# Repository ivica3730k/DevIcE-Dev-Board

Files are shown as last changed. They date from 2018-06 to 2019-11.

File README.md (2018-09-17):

# DevIcE-Development-Board
All software materials for DevIcE Development board,created by Ivica 9A3ICE

IoT development board currently is based on ESP8266,including:
SMPS power supply
16 digital IO ports
6 ADC ports
5 DAC outputs
RTC clock
Optional HC-05 bluetooth

...all packed in small form factor of 100*60mm.

Board easly programmable trough Arduino IDE

Full board plans available in other Repo.

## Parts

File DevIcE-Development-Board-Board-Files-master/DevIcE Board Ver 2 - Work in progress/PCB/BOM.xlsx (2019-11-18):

Schematic Reference | Manufacter | Part Number | Value | Description
J1 | Wurth Eletronics Inc. | ‎694106301002 (https://www.digikey.com/product-detail/en/wurth-electronics-inc/694106301002/732-5930-ND/5047522) |  | DC-IN JACK
U1 | Vishay Siliconix | SI2301CDS-T1-GE3CT-ND |  | MOSFET P-CH 20V 3.1A SOT23-3
D1 | Comchip Technology | ‎CDBA340-HF (https://www.digikey.com/product-detail/en/comchip-technology/CDBA340-HF/641-1748-1-ND/5400722) | 40V 3A | DIODE SCHOTTKY 40V 3A DO214AC
IC1 | Texas Instruments‎ | ‎LM2575S-3.3/NOPB‎ | 3.3V 1A | LM2575-3V3 PSU
L1 | ‎Bourns Inc.‎ | ‎SRR1280-331K (https://www.digikey.com/product-detail/en/bourns-inc/SRR1280-331K/SRR1280-331KLCT-ND/2127441) | 330uH | FIXED IND 330UH 1.1A 600 MOHM
ZD1 | Panasonic Electronic Components‎ | ‎DZ2J100M0L (https://www.digikey.com/product-detail/en/panasonic-electronic-components/DZ2J100M0L/DZ2J100M0LCT-ND/2214312) | 10V | DIODE ZENER 10V 200MW SMINI2
R1 | Vishay Dale‎ | CRCW020110K0FKED | 10K | RES SMD 10K OHM 1% 1/20W 0201
R2 | Vishay Dale‎ | ‎CRCW0201100RFKED (https://www.digikey.com/product-detail/en/vishay-dale/CRCW0201100RFKED/541-100AABCT-ND/1968157) | 100R | RES SMD 100 OHM 1% 1/20W 0201
R3 | Vishay Dale‎ | ‎CRCW02014K70FKED‎ | 4K7 | RES SMD 4.7K OHM 1% 1/20W 0201
R4 | Vishay Dale‎ | ‎CRCW02014K70FKED‎ | 4K7 | RES SMD 4.7K OHM 1% 1/20W 0201
R5 | Vishay Dale‎ | ‎CRCW02014K70FKED‎ | 4K7 | RES SMD 4.7K OHM 1% 1/20W 0201
R6 | Vishay Dale‎ | ‎CRCW02014K70FKED‎ | 4K7 | RES SMD 4.7K OHM 1% 1/20W 0201
U2 | Panasonic Electronic Components‎ | ‎EXB-38V103JV (https://www.digikey.com/product-detail/en/panasonic-electronic-components/EXB-38V103JV/Y9103CT-ND/256604) | 4X10K | RES ARRAY 4 RES 10K OHM 1206
U3 | Panasonic Electronic Components‎ | ‎EXB-38V103JV (https://www.digikey.com/product-detail/en/panasonic-electronic-components/EXB-38V103JV/Y9103CT-ND/256604) | 4X10K | RES ARRAY 4 RES 10K OHM 1206
U4 | Panasonic Electronic Components‎ | ‎EXB-38V103JV (https://www.digikey.com/product-detail/en/panasonic-electronic-components/EXB-38V103JV/Y9103CT-ND/256604) | 4X10K | RES ARRAY 4 RES 10K OHM 1206
IC2 | ‎Microchip Technology‎ | ‎MCP23017T-E/SO‎ |  | IC I/O EXPANDER I2C 16B 28SOIC
IC3 | ‎NXP USA Inc.‎ | ‎PCA9685PW,118 (https://www.digikey.com/product-detail/en/nxp-usa-inc/PCA9685PW,118/568-11925-1-ND/5221902) |  | IC LED DRIVER RGBA 28-TSSOP
C1 | Panasonic Electronic Components‎ | ‎EEE-1HA470XP‎ | 47uF 50V | CAP ALUM 47UF 20% 50V SMD
C2 | ‎Samsung Electro-Mechanics‎ | ‎CL03A104KQ3NNNC (https://www.digikey.com/product-detail/en/samsung-electro-mechanics/CL03A104KQ3NNNC/1276-1013-1-ND/3889099) | 100nF 6.3V | CAP CER 0.1UF 6.3V X5R 0201
C3 | ‎Samsung Electro-Mechanics‎ | ‎CL03A104KQ3NNNC (https://www.digikey.com/product-detail/en/samsung-electro-mechanics/CL03A104KQ3NNNC/1276-1013-1-ND/3889099) | 100nF 6.3V | CAP CER 0.1UF 6.3V X5R 0201
C4 | Panasonic Electronic Components‎ | ‎EEE-0JA221WP‎ | 220uF 6.3V | CAP ALUM 220UF 20% 6.3V SMD
C5 | Panasonic Electronic Components‎ | ‎EEE-0JA221WP‎ | 220uF 6.3V | CAP ALUM 220UF 20% 6.3V SMD
LED1 | ‎Kingbright‎ | ‎APTR3216CGCK (https://www.digikey.com/product-detail/en/kingbright/APTR3216CGCK/754-1167-1-ND/1747884) | GRN | LED GREEN CLEAR CHIP SMD

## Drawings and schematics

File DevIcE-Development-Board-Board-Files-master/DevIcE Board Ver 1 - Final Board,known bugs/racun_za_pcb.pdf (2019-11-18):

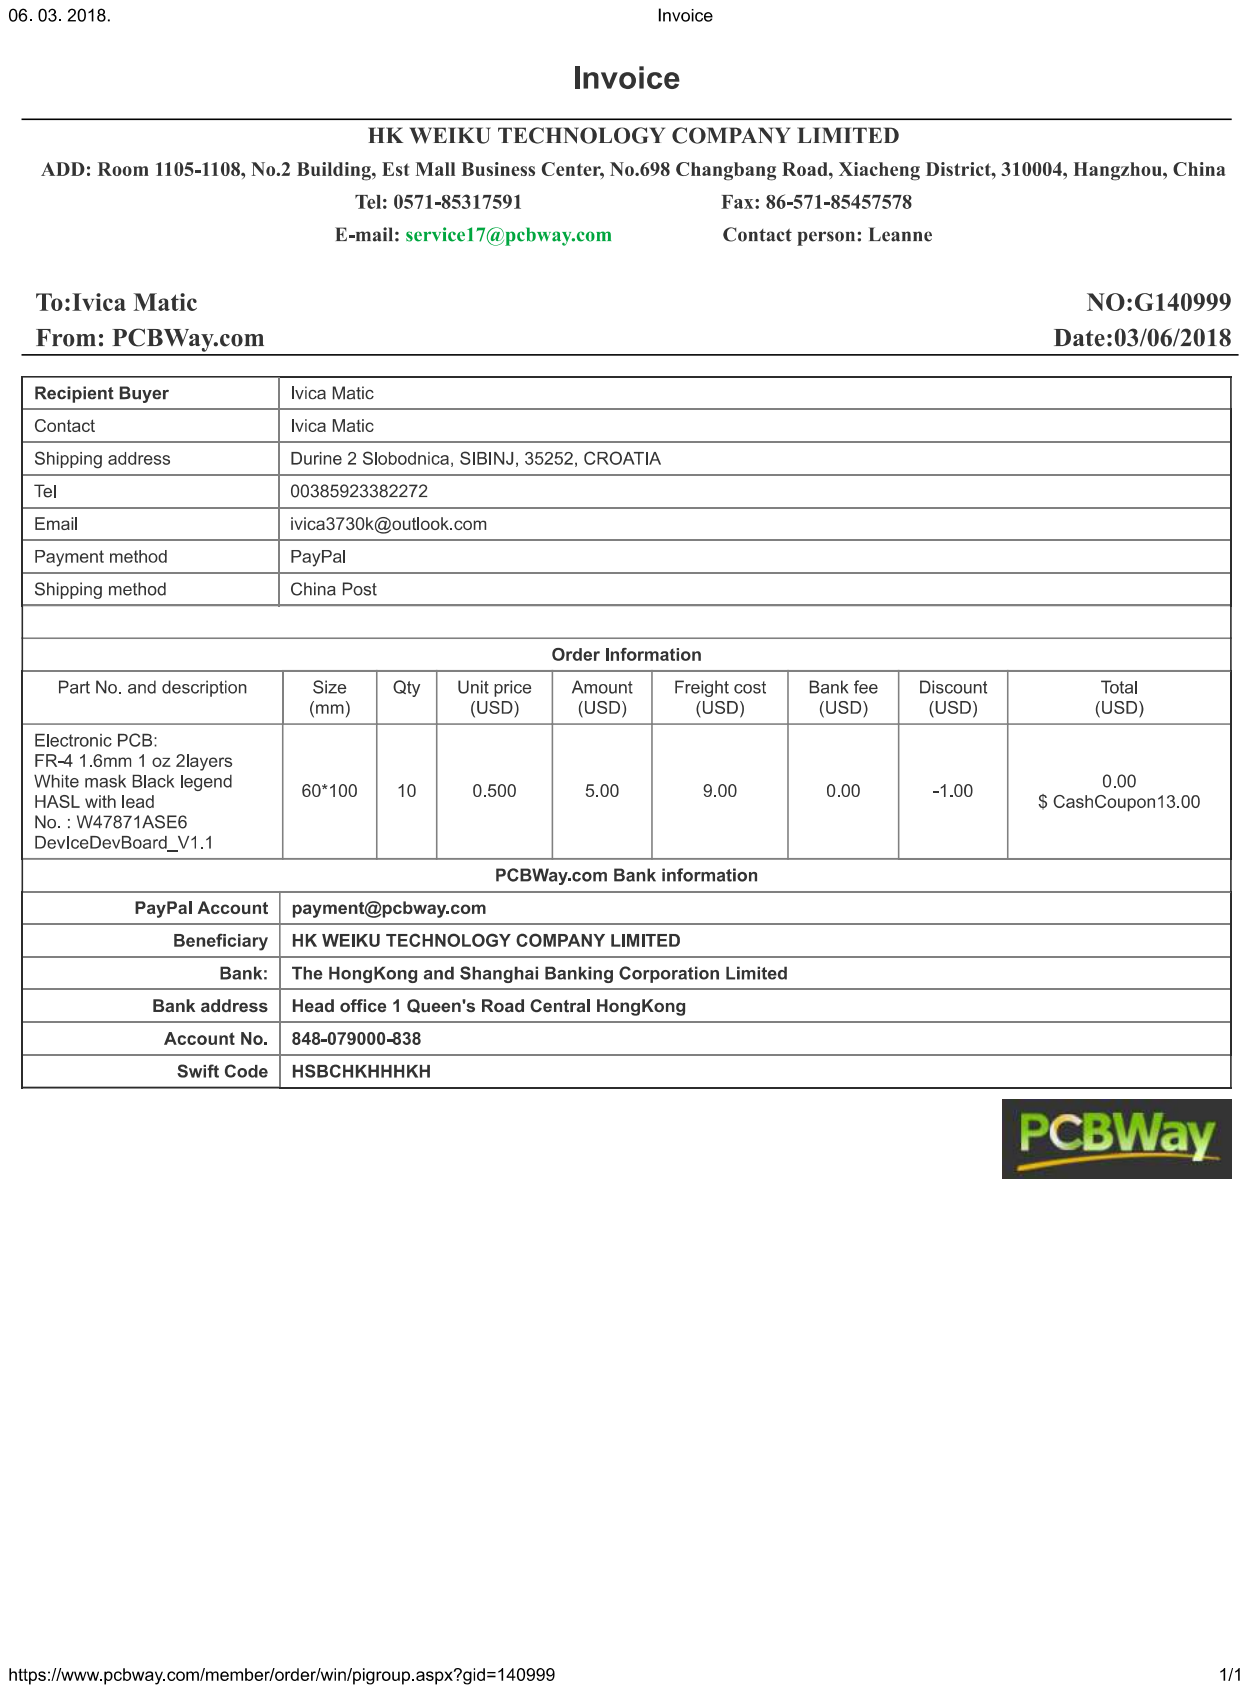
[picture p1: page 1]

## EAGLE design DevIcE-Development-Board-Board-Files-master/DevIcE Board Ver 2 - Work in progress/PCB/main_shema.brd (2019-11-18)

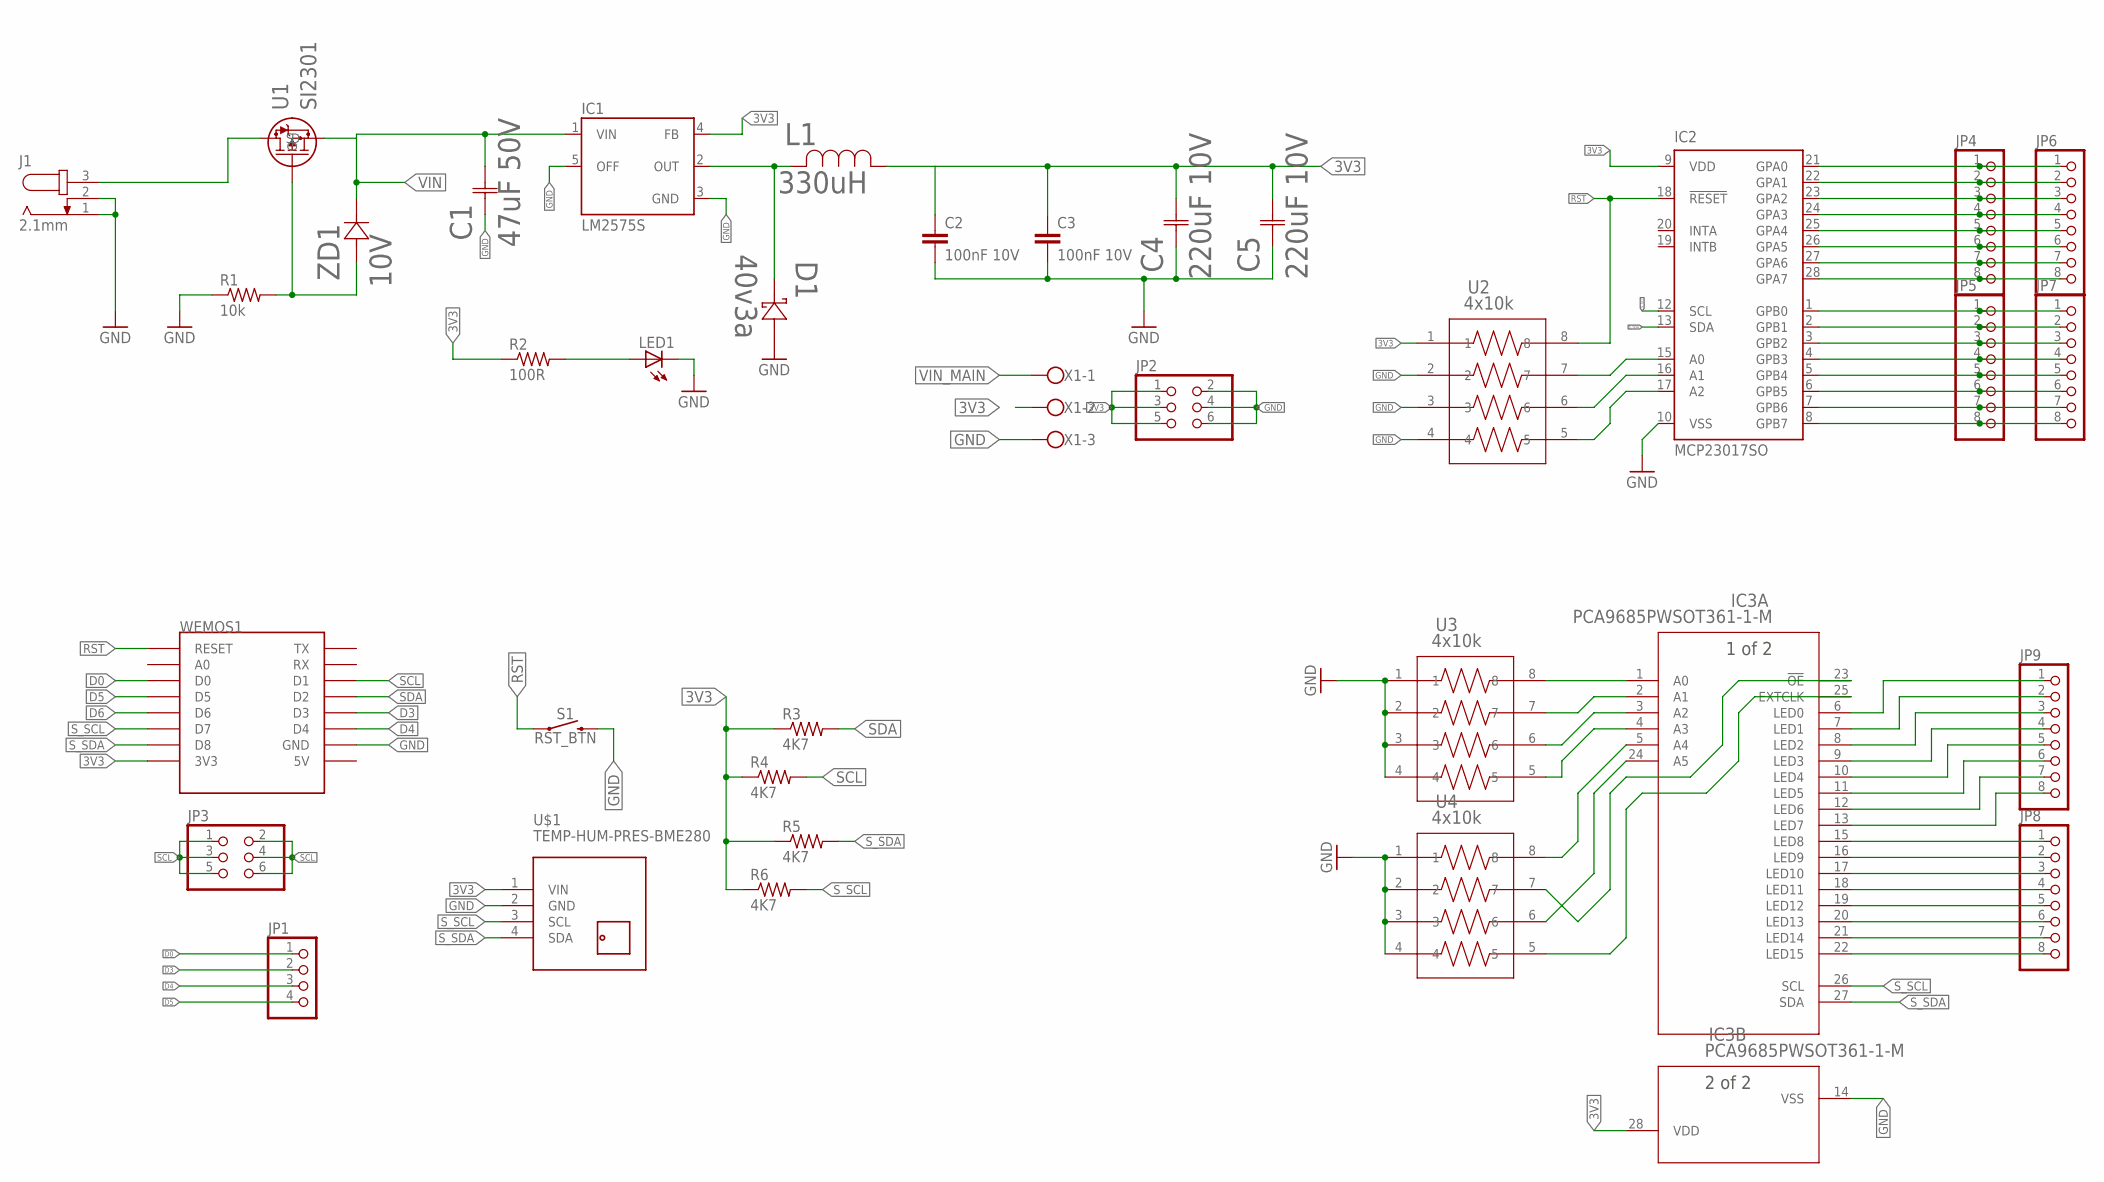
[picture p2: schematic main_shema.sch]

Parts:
C1: 47uF 50V; CAP_EEE_D8-M
C2, C3: 100nF 10V; C0603
C4, C5: 220uF 10V; CAP_EEE_D-M
D1: 40v3a; CDBA-HF-M
IC1: LM2575S; TO263-5
IC2: MCP23017SO; SO28W
IC3: PCA9685PWSOT361-1-M; SOT361-1-M
J1: 2.1mm; SPC4078
JP1: PINHD-1X4; 1X04
JP2, JP3: PINHD-2X3; 2X03
JP4, JP5, JP6, JP7: PINHD-1X8; 1X08
JP8, JP9: PINHD-1X8/LONG; 1X08
L1: 330uH; IND_BOURNS_SRR1280
LED1: LED_E; LED_1206
R1: 10k; R0603
R2: 100R; R0603
R3, R4, R5, R6: 4K7; R0603
S1: RST_BTN; TACTILE_SWITCH_PTH_6.0MM
U1: SI2301; TO-236-M
U2: 4x10k; C_ARRAY_EXB38V
U3, U4: 4x10k; C_ARRAY_EXB38V-M
U$1: TEMP-HUM-PRES-BME280
WEMOS1: WEMOS-D1-MINI
X1: W237-103
ZD1: 10V; SMINI2-F5-B-M

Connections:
3V3: C2.1, C3.1, C4.2 (22), C5.2 (22), IC1.4 (FB), IC2.9 (VDD), IC3.28 (VDD), JP2.1, JP2.3, JP2.5, L1.1, R2.1, R3.1, R4.1, R5.1, R6.1, U2.1, U$1.1 (VIN), WEMOS1.3V3, X1.2
D0: JP1.1, WEMOS1.D0
D3: JP1.2, WEMOS1.D3
D4: JP1.3, WEMOS1.D4
D5: JP1.4, WEMOS1.D5
D6: WEMOS1.D6
GND: C1.1 (11), C2.2, C3.2, C4.1 (11), C5.1 (11), D1.2 (22), IC1.3 (GND), IC1.5 (OFF), IC2.10 (VSS), IC3.14 (VSS), J1.1, J1.2, JP2.2, JP2.4, JP2.6, LED1.C, R1.1, S1.3 (2), U2.2, U2.3, U2.4, U3.1, U3.2, U3.3, U3.4, U4.1, U4.2, U4.3, U4.4, U$1.2 (GND), WEMOS1.GND, X1.3
unnamed: LED1.A, R2.2
unnamed: R1.2, U1.1 (G), ZD1.2 (22)
unnamed: IC2.21 (GPA0), JP4.1, JP6.1
unnamed: IC2.22 (GPA1), JP4.2, JP6.2
unnamed: IC3.6 (LED0), JP9.1
unnamed: IC3.7 (LED1), JP9.2
unnamed: IC3.8 (LED2), JP9.3
unnamed: D1.1 (11), IC1.2 (OUT), L1.2
unnamed: IC2.15 (A0), U2.7
unnamed: IC3.9 (LED3), JP9.4
unnamed: IC2.23 (GPA2), JP4.3, JP6.3
unnamed: IC2.16 (A1), U2.6
unnamed: IC2.17 (A2), U2.5
unnamed: IC3.10 (LED4), JP9.5
unnamed: IC2.24 (GPA3), JP4.4, JP6.4
unnamed: IC2.25 (GPA4), JP4.5, JP6.5
unnamed: IC2.26 (GPA5), JP4.6, JP6.6
unnamed: IC3.11 (LED5), JP9.6
unnamed: IC3.12 (LED6), JP9.7
unnamed: IC3.13 (LED7), JP9.8
unnamed: IC2.27 (GPA6), JP4.7, JP6.7
unnamed: IC2.28 (GPA7), JP4.8, JP6.8
unnamed: IC2.1 (GPB0), JP5.1, JP7.1
unnamed: IC2.2 (GPB1), JP5.2, JP7.2
unnamed: IC2.3 (GPB2), JP5.3, JP7.3
unnamed: IC2.4 (GPB3), JP5.4, JP7.4
unnamed: IC2.5 (GPB4), JP5.5, JP7.5
unnamed: IC2.6 (GPB5), JP5.6, JP7.6
unnamed: IC2.7 (GPB6), JP5.7, JP7.7
unnamed: IC2.8 (GPB7), JP5.8, JP7.8
unnamed: IC3.15 (LED8), JP8.1
unnamed: IC3.16 (LED9), JP8.2
unnamed: IC3.17 (LED10), JP8.3
unnamed: IC3.18 (LED11), JP8.4
unnamed: IC3.19 (LED12), JP8.5
unnamed: IC3.20 (LED13), JP8.6
unnamed: IC3.21 (LED14), JP8.7
unnamed: IC3.22 (LED15), JP8.8
unnamed: IC3.1 (A0), U3.8
unnamed: IC3.2 (A1), U3.7
unnamed: IC3.3 (A2), U3.6
unnamed: IC3.4 (A3), U3.5
unnamed: IC3.5 (A4), U4.8
unnamed: IC3.24 (A5), U4.6
unnamed: IC3.23 (!OE), U4.7
unnamed: IC3.25 (EXTCLK), U4.5
RST: IC2.18 (!RESET), S1.1, U2.8, WEMOS1.RESET
SCL: JP3.1, JP3.3, JP3.5, R4.2, WEMOS1.D1
SDA: JP3.2, JP3.4, JP3.6, R3.2, WEMOS1.D2
S_SCL: IC2.12 (SCL), IC3.26 (SCL), R6.2, U$1.3 (SCL), WEMOS1.D7
S_SDA: IC2.13 (SDA), IC3.27 (SDA), R5.2, U$1.4 (SDA), WEMOS1.D8
VIN: C1.2 (22), IC1.1 (VIN), U1.2 (S), ZD1.1 (11)
VIN_MAIN: J1.3, U1.3 (D), X1.1

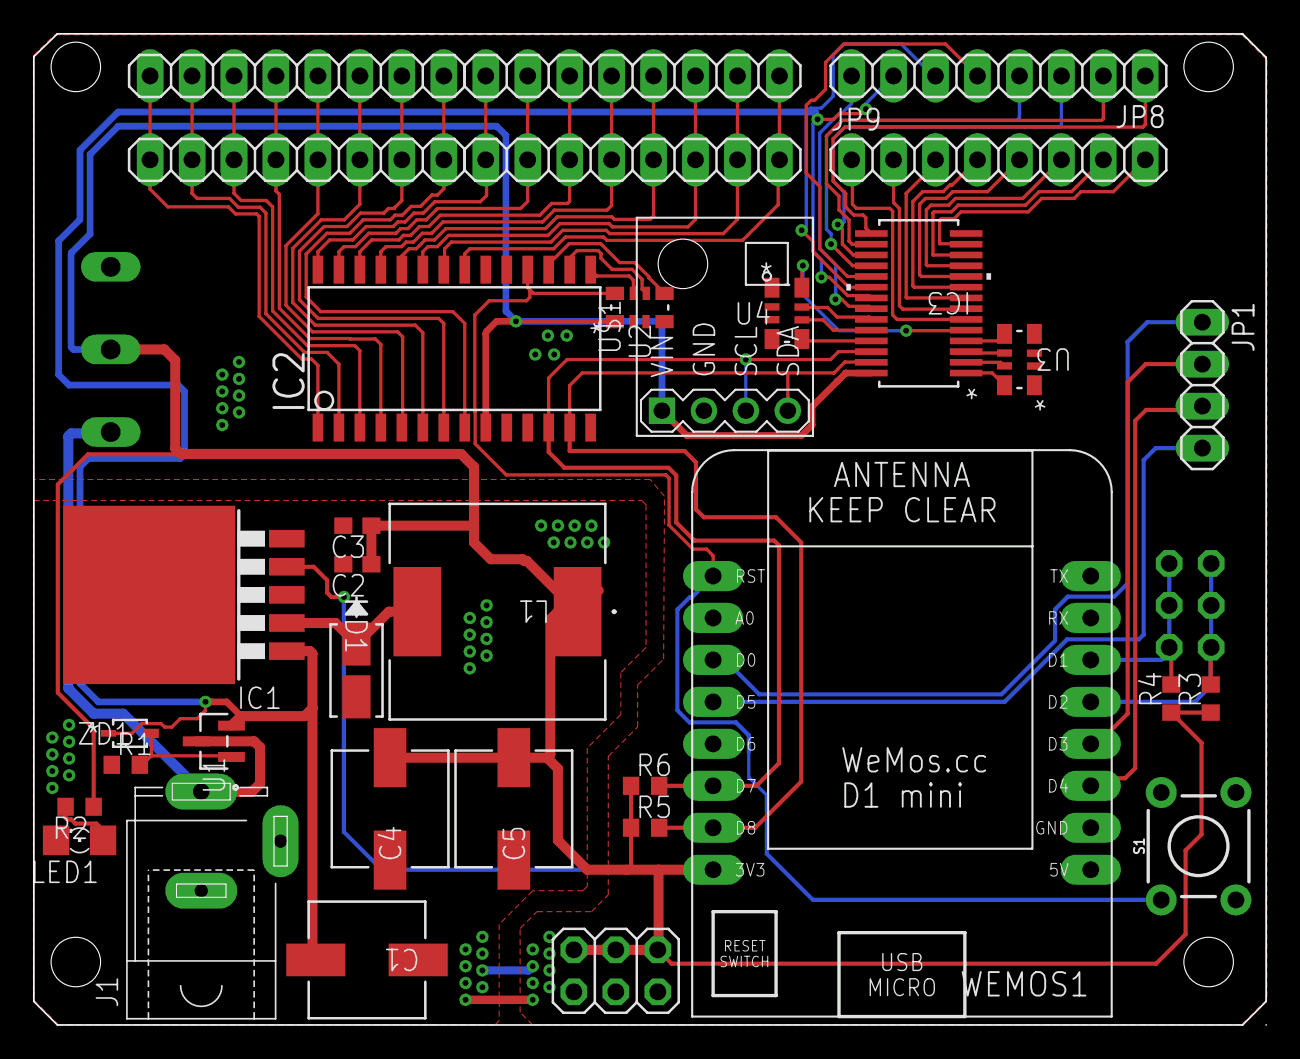
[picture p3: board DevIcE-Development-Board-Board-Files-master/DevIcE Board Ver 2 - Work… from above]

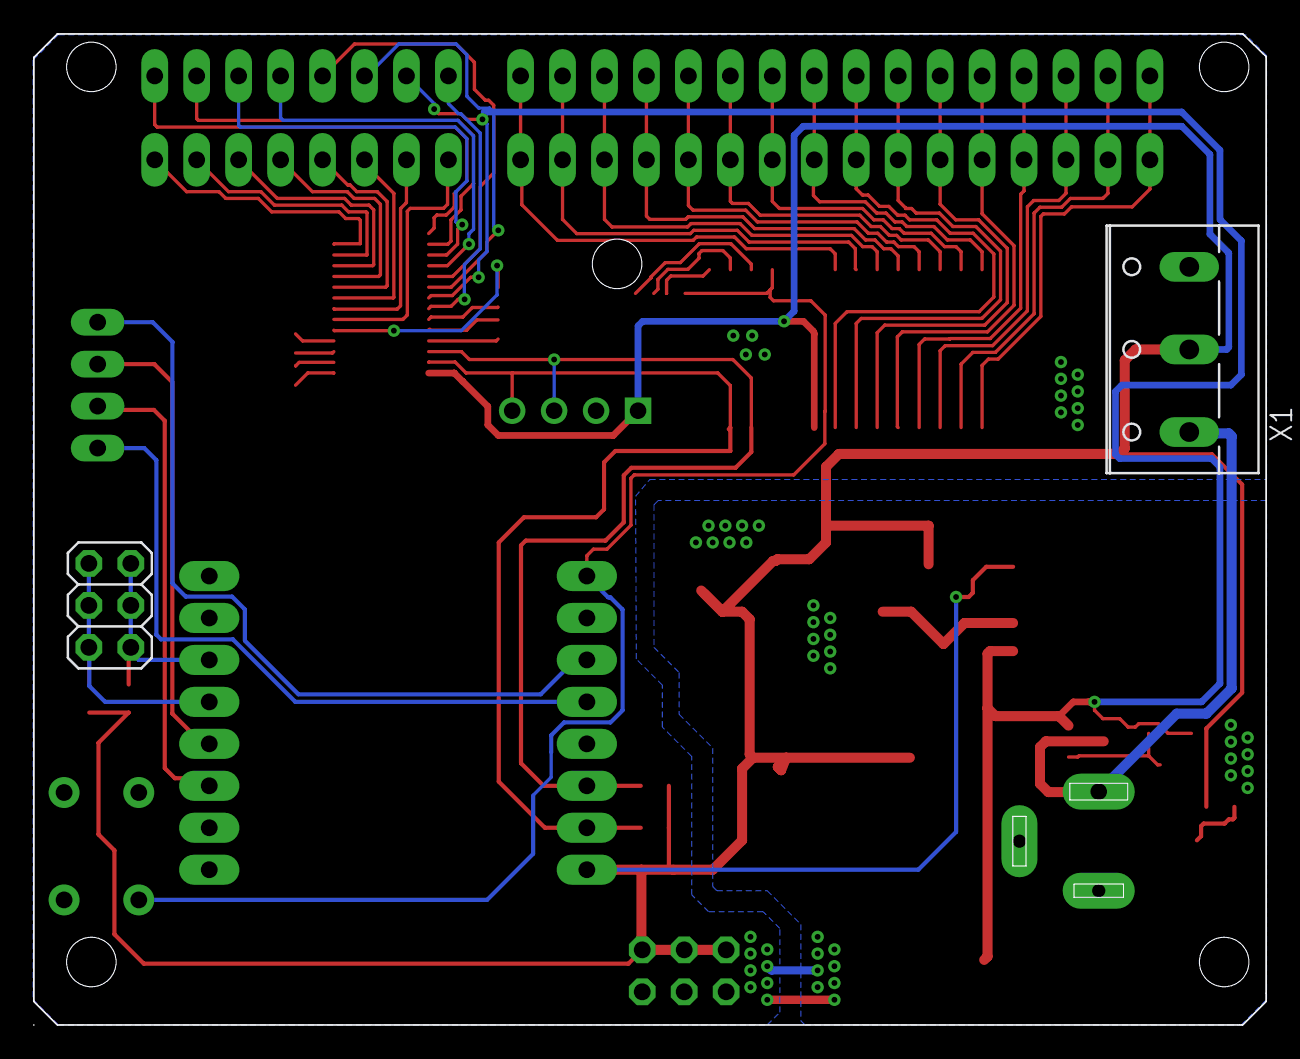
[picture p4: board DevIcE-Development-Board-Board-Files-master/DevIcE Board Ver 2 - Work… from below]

Board: 2 copper layers, 74.6 x 60.0 mm, 36 parts (2 on the bottom side), 59 nets.

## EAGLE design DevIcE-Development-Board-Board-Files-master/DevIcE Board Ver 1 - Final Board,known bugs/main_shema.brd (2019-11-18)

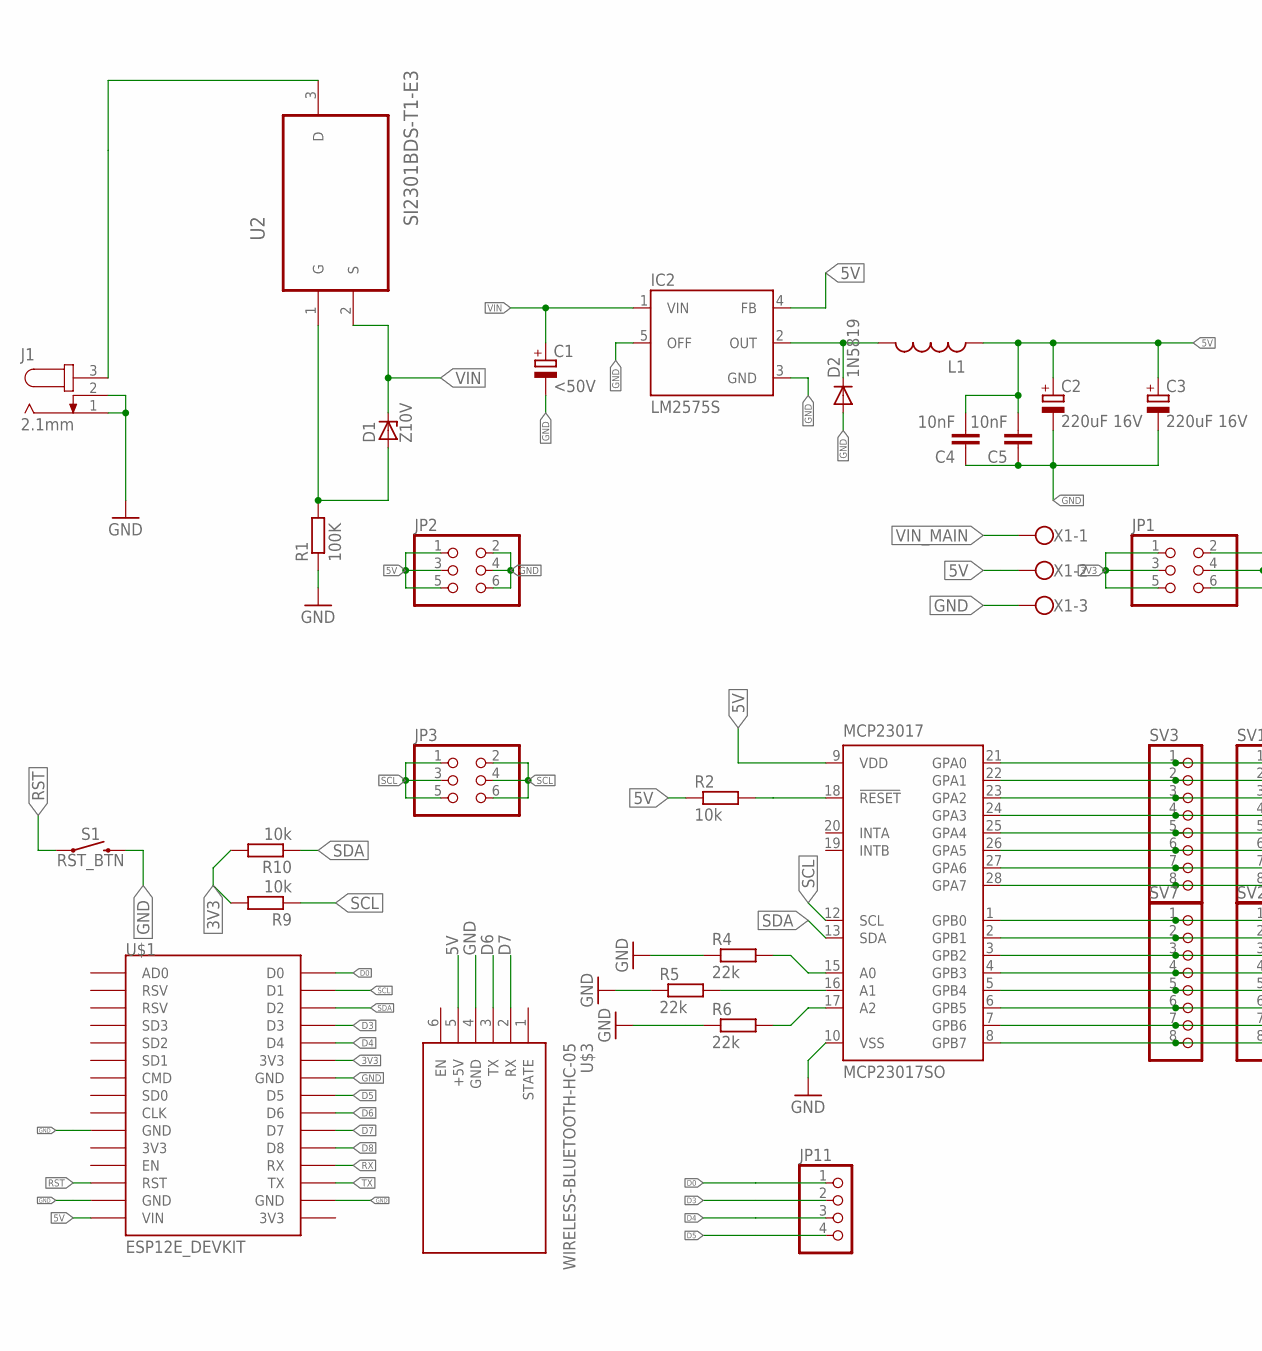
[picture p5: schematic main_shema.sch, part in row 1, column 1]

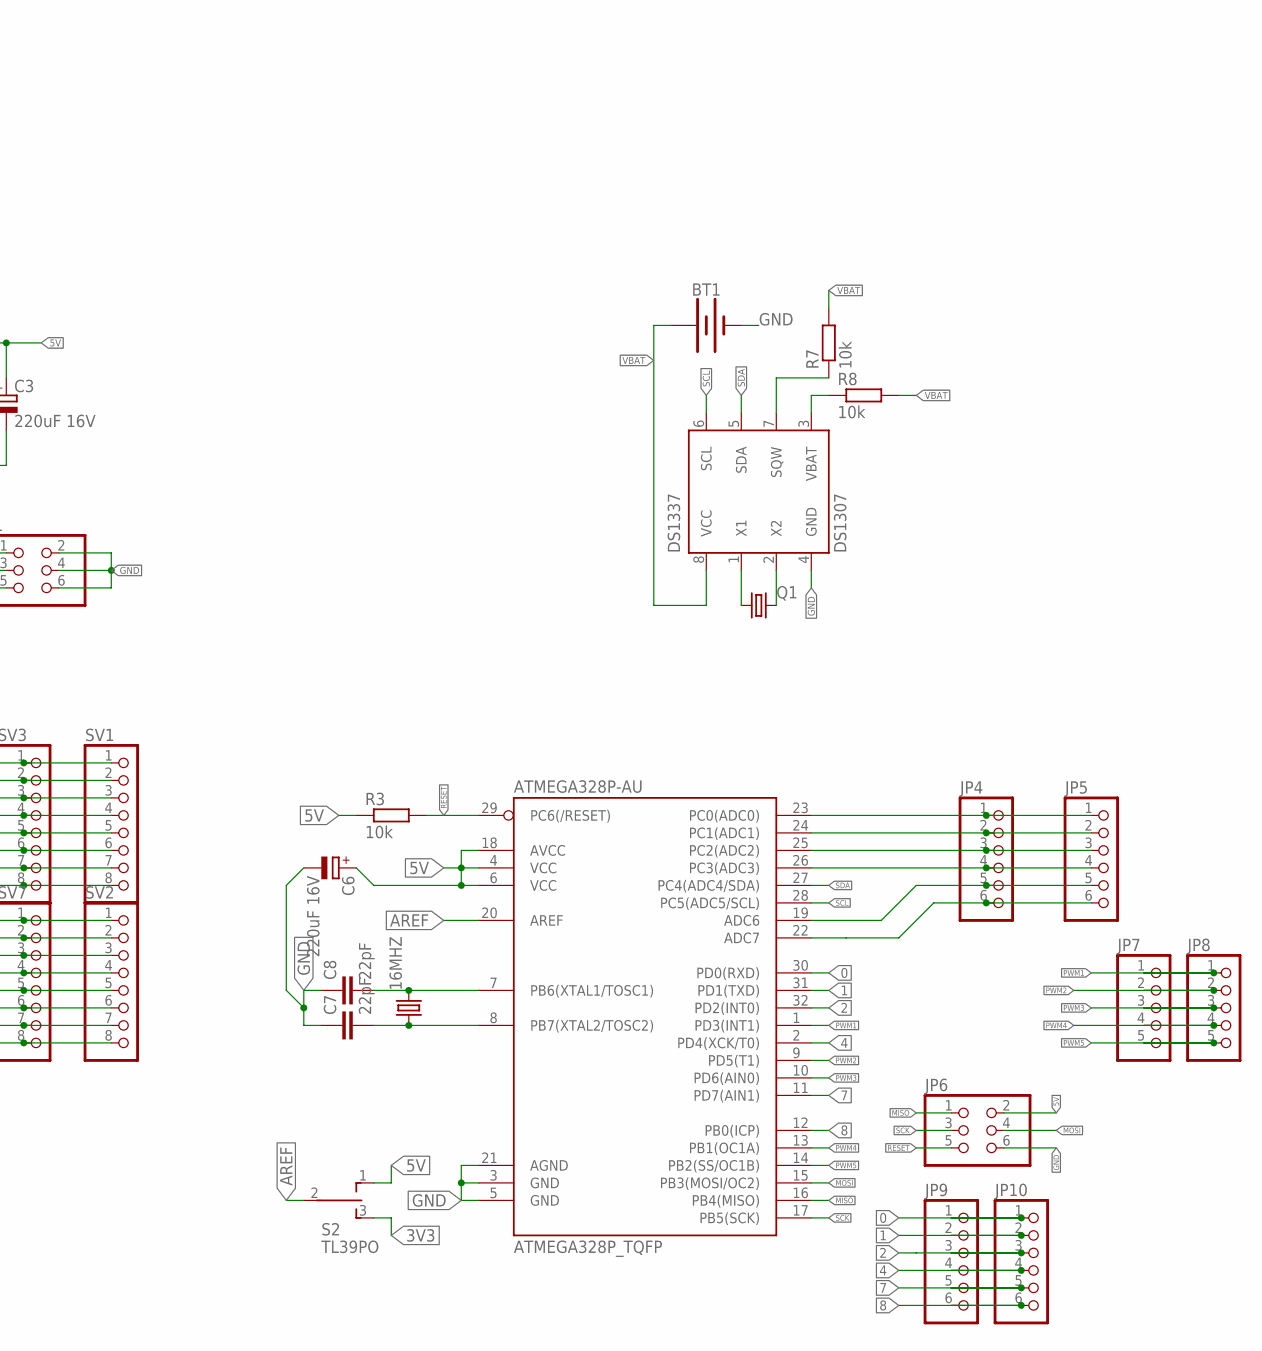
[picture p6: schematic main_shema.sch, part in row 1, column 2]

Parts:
16MHZ: CRYSTALHC49S; HC49/S
ATMEGA328P-AU: ATMEGA328P_TQFP; TQFP32-08
BT1: BATTERY-20MM_PTH; BATTCOM_20MM_PTH
C1: <50V; E3,5-8
C2, C3, C6: 220uF 16V; E2-5
C4, C5: 10nF; C025-024X044
C7, C8: 22pF; C025-024X044
D1: Z10V; DO35Z10
D2: 1N5819; DO41-10
DS1337: DS1307; DIL08
IC2: LM2575S; TO263-5
J1: 2.1mm; SPC4078
JP1, JP2, JP3, JP6: PINHD-2X3; 2X03
JP4, JP5, JP9, JP10: PINHD-1X6; 1X06
JP7, JP8: PINHD-1X5; 1X05
JP11: PINHD-1X4; 1X04
L1: MSS1260
MCP23017: MCP23017SO; SO28W
Q1: CRYSTALTC38H; TC38H
R1: 100K; R1206
R2, R3, R7, R8, R9, R10: 10k; R1206
R4, R5, R6: 22k; R1206
S1: RST_BTN; TACTILE_SWITCH_PTH_6.0MM
S2: TL39PO; TL3XPO
SV1, SV2, SV3, SV7: PINHD-1X8; 1X08
U2: SI2301BDS-T1-E3; SOT95P237X112-3N
U$1: ESP12E_DEVKIT
U$3: WIRELESS-BLUETOOTH-HC-05
X1: W237-103

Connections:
0: ATMEGA328P-AU.30 (PD0(RXD)), JP9.1, JP10.1
1: ATMEGA328P-AU.31 (PD1(TXD)), JP9.2, JP10.2
2: ATMEGA328P-AU.32 (PD2(INT0)), JP9.3, JP10.3
3V3: JP1.1, JP1.3, JP1.5, R9.2, R10.2, S2.3 (S), U$1.3V3@1 (3V3)
4: ATMEGA328P-AU.2 (PD4(XCK/T0)), JP9.4, JP10.4
5V: ATMEGA328P-AU.4 (VCC), ATMEGA328P-AU.6 (VCC), ATMEGA328P-AU.18 (AVCC), C2.+, C3.+, C4.2, C5.2, C6.+, IC2.4 (FB), JP2.1, JP2.3, JP2.5, JP6.2, L1.P$2, MCP23017.9 (VDD), R2.1, R3.1, S2.1 (O), U$1.VIN, U$3.5 (+5V), X1.2
7: ATMEGA328P-AU.11 (PD7(AIN1)), JP9.5, JP10.5
8: ATMEGA328P-AU.12 (PB0(ICP)), JP9.6, JP10.6
AREF: ATMEGA328P-AU.20 (AREF), S2.2
D0: JP11.1, U$1.D0
D3: JP11.2, U$1.D3
D4: JP11.3, U$1.D4
D5: JP11.4, U$1.D5
D6: U$1.D6, U$3.3 (TX)
D7: U$1.D7, U$3.2 (RX)
D8: U$1.D8
GND: ATMEGA328P-AU.3 (GND), ATMEGA328P-AU.5 (GND), ATMEGA328P-AU.21 (AGND), BT1.2 (-), C1.-, C2.-, C3.-, C4.1, C5.1, C6.-, C7.1, C8.1, D2.A, DS1337.4 (GND), IC2.3 (GND), IC2.5 (OFF), J1.1, J1.2, JP1.2, JP1.4, JP1.6, JP2.2, JP2.4, JP2.6, JP6.6, MCP23017.10 (VSS), R1.1, R4.1, R5.1, R6.1, S1.3 (2), U$1.GND@0 (GND), U$1.GND@1 (GND), U$1.GND@2 (GND), U$1.GND@3 (GND), U$3.4 (GND), X1.3
MISO: ATMEGA328P-AU.16 (PB4(MISO)), JP6.1
MOSI: ATMEGA328P-AU.15 (PB3(MOSI/OC2)), JP6.4
unnamed: DS1337.1 (X1), Q1.1
unnamed: D1.A, R1.2, U2.1 (G)
unnamed: MCP23017.21 (GPA0), SV1.1, SV3.1
unnamed: MCP23017.22 (GPA1), SV1.2, SV3.2
unnamed: MCP23017.15 (A0), R4.2
unnamed: MCP23017.16 (A1), R5.2
unnamed: MCP23017.17 (A2), R6.2
unnamed: D2.C, IC2.2 (OUT), L1.P$1
unnamed: DS1337.2 (X2), Q1.2
unnamed: ATMEGA328P-AU.22 (ADC7), JP4.6, JP5.6
unnamed: MCP23017.23 (GPA2), SV1.3, SV3.3
unnamed: DS1337.3 (VBAT), R8.1
unnamed: DS1337.7 (SQW), R7.1
unnamed: MCP23017.24 (GPA3), SV1.4, SV3.4
unnamed: MCP23017.25 (GPA4), SV1.5, SV3.5
unnamed: MCP23017.26 (GPA5), SV1.6, SV3.6
unnamed: MCP23017.18 (!RESET), R2.2
unnamed: 16MHZ.2, ATMEGA328P-AU.7 (PB6(XTAL1/TOSC1)), C8.2
unnamed: 16MHZ.1, ATMEGA328P-AU.8 (PB7(XTAL2/TOSC2)), C7.2
unnamed: MCP23017.27 (GPA6), SV1.7, SV3.7
unnamed: MCP23017.28 (GPA7), SV1.8, SV3.8
unnamed: MCP23017.1 (GPB0), SV2.1, SV7.1
unnamed: MCP23017.2 (GPB1), SV2.2, SV7.2
unnamed: MCP23017.3 (GPB2), SV2.3, SV7.3
unnamed: MCP23017.4 (GPB3), SV2.4, SV7.4
unnamed: MCP23017.5 (GPB4), SV2.5, SV7.5
unnamed: MCP23017.6 (GPB5), SV2.6, SV7.6
unnamed: MCP23017.7 (GPB6), SV2.7, SV7.7
unnamed: MCP23017.8 (GPB7), SV2.8, SV7.8
unnamed: ATMEGA328P-AU.23 (PC0(ADC0)), JP4.1, JP5.1
unnamed: ATMEGA328P-AU.24 (PC1(ADC1)), JP4.2, JP5.2
unnamed: ATMEGA328P-AU.25 (PC2(ADC2)), JP4.3, JP5.3
unnamed: ATMEGA328P-AU.26 (PC3(ADC3)), JP4.4, JP5.4
unnamed: ATMEGA328P-AU.19 (ADC6), JP4.5, JP5.5
PWM1: ATMEGA328P-AU.1 (PD3(INT1)), JP7.1, JP8.1
PWM2: ATMEGA328P-AU.9 (PD5(T1)), JP7.2, JP8.2
PWM3: ATMEGA328P-AU.10 (PD6(AIN0)), JP7.3, JP8.3
PWM4: ATMEGA328P-AU.13 (PB1(OC1A)), JP7.4, JP8.4
PWM5: ATMEGA328P-AU.14 (PB2(SS/OC1B)), JP7.5, JP8.5
RESET: ATMEGA328P-AU.29 (PC6(/RESET)), JP6.5, R3.2
RST: S1.1, U$1.RST
RX: U$1.RX
SCK: ATMEGA328P-AU.17 (PB5(SCK)), JP6.3
SCL: ATMEGA328P-AU.28 (PC5(ADC5/SCL)), DS1337.6 (SCL), JP3.1, JP3.3, JP3.5, MCP23017.12 (SCL), R9.1, U$1.D1
SDA: ATMEGA328P-AU.27 (PC4(ADC4/SDA)), DS1337.5 (SDA), JP3.2, JP3.4, JP3.6, MCP23017.13 (SDA), R10.1, U$1.D2
TX: U$1.TX
VBAT: BT1.1 (+), DS1337.8 (VCC), R7.2, R8.2
VIN: C1.+, D1.C, IC2.1 (VIN), U2.2 (S)
VIN_MAIN: J1.3, U2.3 (D), X1.1

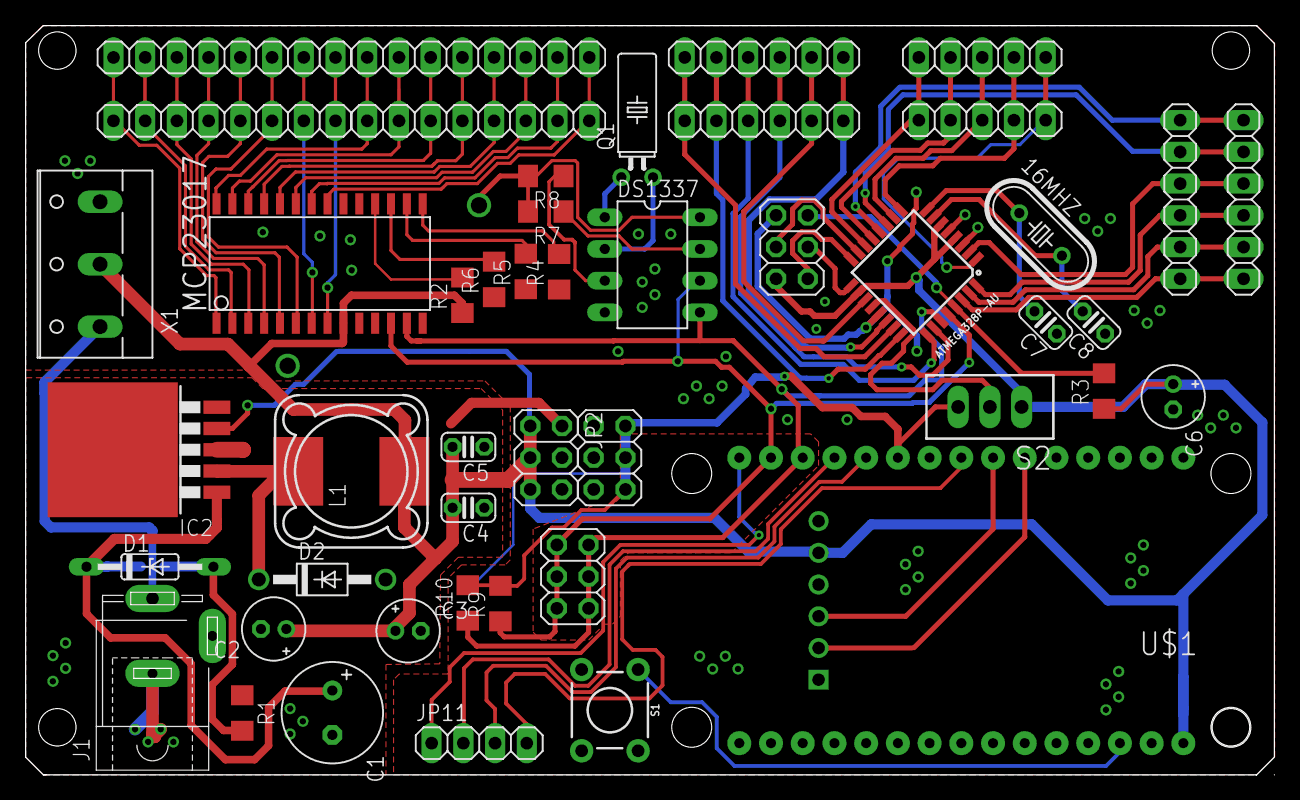
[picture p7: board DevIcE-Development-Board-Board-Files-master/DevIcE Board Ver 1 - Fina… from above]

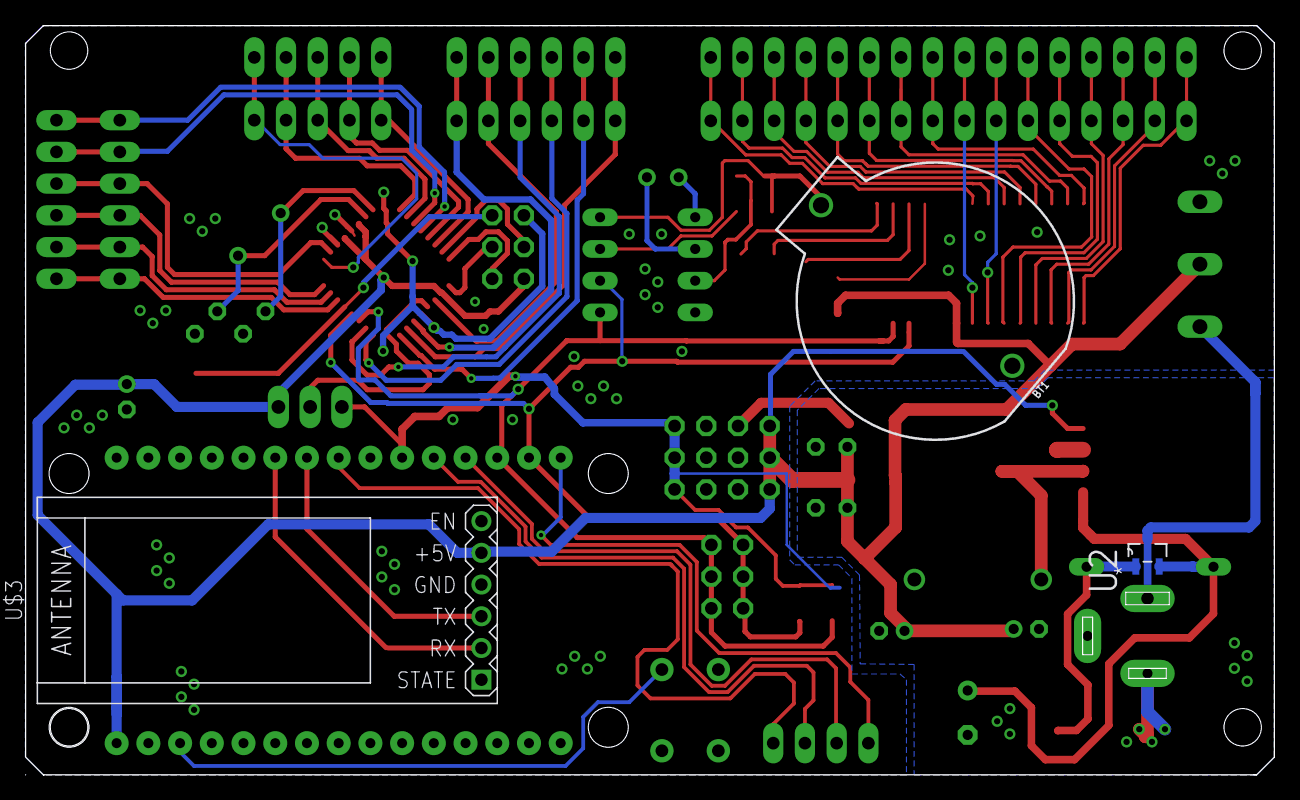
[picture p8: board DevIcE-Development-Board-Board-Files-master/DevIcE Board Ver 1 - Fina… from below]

Board: 2 copper layers, 100.0 x 60.0 mm, 50 parts (3 on the bottom side), 65 nets.

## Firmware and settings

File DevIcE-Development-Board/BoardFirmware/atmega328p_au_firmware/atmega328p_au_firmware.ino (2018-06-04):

#include <Wire.h>
long millisa, millisb = 0;
byte pwm_data[6];
float adc1,adc2,adc3,adc4,adc5,adc6;
char buffer [sizeof(adc1+adc2+adc3+adc4+adc5+adc6)];

void setup()

{    
  analogReference(EXTERNAL);
    pinMode(A0, INPUT);
    pinMode(A1, INPUT);
    pinMode(A2, INPUT);
    
    pinMode(A3, INPUT);
    pinMode(A6, INPUT);
    pinMode(A7, INPUT);
    pinMode(3, OUTPUT);
    pinMode(5, OUTPUT);
    pinMode(9, OUTPUT);
    pinMode(10, OUTPUT);
    pinMode(11, OUTPUT);
      pinMode(8,OUTPUT);
      //analogWrite(3,127);
    Wire.begin(10);
    Wire.onRequest(reqEvent);
    Serial.begin(9600);
    Wire.onReceive(receiveEvent);
}

void loop(){
  
millisa = millis();
if(millisa-millisb >= 100){

  adc1 = analogRead(A0);
  adc2 =analogRead(A1);
  adc3 =analogRead(A2);
  adc4=analogRead(A3);
  adc5=analogRead(A6);
  adc6=analogRead(A7);



memcpy(&buffer[0],&adc1,sizeof(adc1));
memcpy(&buffer[4],&adc2,sizeof(adc2));

memcpy(&buffer[8],&adc3,sizeof(adc3));
memcpy(&buffer[12],&adc4,sizeof(adc4));


memcpy(&buffer[16],&adc5,sizeof(adc5));
memcpy(&buffer[20],&adc6,sizeof(adc6));

  millisb = millis();
  
  }

}


void reqEvent()
{


  for(int i = 0;i<24;i++){
  Wire.write(buffer[i]);

  }

}

void receiveEvent()
{
    while (Wire.available()) { 
        for (byte i = 0; i < 6; i++) {
            pwm_data[i] = Wire.read(); 
        }
    }
    
analogWrite(3, pwm_data[0]);
analogWrite(5, pwm_data[1]);
analogWrite(6, pwm_data[2]);
analogWrite(9, pwm_data[3]);
analogWrite(10, pwm_data[4]);
analogWrite(11, pwm_data[5]);

}

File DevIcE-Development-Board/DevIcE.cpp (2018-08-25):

#include <Arduino.h>
#include "Adafruit_MCP23017.h"
#include <Wire.h>
#include "RTClib.h"
#include "DevIcE.h"
#define atmega_adr 10


char buffer[24];

float adc_data[6]; // drzi adc podatke primljene sa atmega chipa
unsigned int pwm_data[6];

Adafruit_MCP23017 mcp1;
RTC_DS1307 rtc;



int godina,mjesec,dan,sat,minuta,sekunda = 0;



void i2c_read()
{
 
  Wire.requestFrom(atmega_adr, 24);
  while (Wire.available())
  {
    for(int i = 0;i<24;i++){
      buffer[i] = Wire.read();
   
      }
  }
  
}


 unsigned int ADC_read(int pin)
{

    i2c_read();

    
char buffer_adc1[4];
buffer_adc1 [0] = buffer[0];
buffer_adc1 [1] = buffer[1];
buffer_adc1 [2] = buffer[2];
buffer_adc1 [3] = buffer[3];
adc_data [0] = *(float *)&buffer_adc1;


char buffer_adc2[4];
int ofset = 4;
buffer_adc2 [0] = buffer[0+ofset];
buffer_adc2 [1] = buffer[1+ofset];
buffer_adc2 [2] = buffer[2+ofset];
buffer_adc2 [3] = buffer[3+ofset];
adc_data [1] = *(float *)&buffer_adc2;

char buffer_adc3[4];
 ofset = 8;
buffer_adc3 [0] = buffer[0+ofset];
buffer_adc3 [1] = buffer[1+ofset];
buffer_adc3 [2] = buffer[2+ofset];
buffer_adc3 [3] = buffer[3+ofset];
adc_data [2] = *(float *)&buffer_adc3;

char buffer_adc4[4];
 ofset = 12;
buffer_adc4 [0] = buffer[0+ofset];
buffer_adc4 [1] = buffer[1+ofset];
buffer_adc4 [2] = buffer[2+ofset];
buffer_adc4 [3] = buffer[3+ofset];
adc_data [3] = *(float *)&buffer_adc4;


char buffer_adc5[4];
 ofset = 16;
buffer_adc5 [0] = buffer[0+ofset];
buffer_adc5 [1] = buffer[1+ofset];
buffer_adc5 [2] = buffer[2+ofset];
buffer_adc5 [3] = buffer[3+ofset];
adc_data [4] = *(float *)&buffer_adc5;

char buffer_adc6[4];
 ofset = 20;
buffer_adc6 [0] = buffer[0+ofset];
buffer_adc6 [1] = buffer[1+ofset];
buffer_adc6 [2] = buffer[2+ofset];
buffer_adc6 [3] = buffer[3+ofset];
adc_data [5] = *(float *)&buffer_adc6;



    unsigned int val =  adc_data[(pin - 1)];
    return val;
}

unsigned int IO_read(int pin)
{
    int x;
    unsigned int state;
  

        if (pin <= 8) {
            x = map(pin, 1, 8, 8, 15);
            mcp1.pinMode(x, INPUT_PULLUP);
            state = mcp1.digitalRead(x);
        }

        if (pin > 8) {
            x = map(pin, 8, 16, 7, 0);
            mcp1.pinMode(x, INPUT_PULLUP);
            state = mcp1.digitalRead(x);
        }

        return (state);
    }


void IO_write(int pin, int state)
{

  
    int x;

   

        if (pin <= 8) {
            x = map(pin, 1, 8, 8, 15);
            mcp1.pinMode(x, OUTPUT);
            mcp1.digitalWrite(x, state);
        }

        if (pin > 8) {
            x = map(pin, 8, 16, 7, 0);
            mcp1.pinMode(x, OUTPUT);
            mcp1.digitalWrite(x, state);
        }
    
}

void send_pwm(){
   byte vals[6] = {pwm_data[0],pwm_data[1],pwm_data[2],pwm_data[3],pwm_data[4],pwm_data[5]};     
              Wire.beginTransmission(atmega_adr);
              Wire.write(vals,6);
              Wire.endTransmission();
  }

void PWM_write(int pin,int val){
  
  pin = pin-1; //uzima pwm vrijednost od korisnika preko esp cipa i salje,preko funkcije send_pwm na atmega chip
  pwm_data[pin] = val;
  send_pwm();

  
  }

void read_time(){
  
    DateTime now = rtc.now();
    godina = now.year();
    mjesec = now.month();
    dan = now.day();
    sat = now.hour();
    minuta = now.minute();
    sekunda = now.second();
  }

String vrati_mjesec(){
    DateTime now = rtc.now();
    int mjesec = now.month();
    String vrati;
    if(mjesec <10){
      vrati += "0";
      vrati += mjesec;
      return(vrati);
      }
      else{
      vrati += mjesec;
      return(vrati);
      }
  }

String vrati_dan(){
    DateTime now = rtc.now();
    int dan = now.day();
    String vrati;
    if(dan <10){
      vrati += "0";
      vrati += dan;
      return(vrati);
      }
      else{
      vrati += dan;
      return(vrati);
      }
  }

String vrati_godinu(){
    DateTime now = rtc.now();
    int godina = now.year();
    String vrati;
    vrati += godina;
    return(vrati);
      }


String vrati_sekunde(){
    DateTime now = rtc.now();
    int sekunda = now.second();
    String vrati;
    if(sekunda <10){
      vrati += "0";
      vrati += sekunda;
      return(vrati);
      }
      else{
      vrati += sekunda;
      return(vrati);
      }
  }

  String vrati_minute(){
    DateTime now = rtc.now();
    int minuta = now.minute();
    String vrati;
    if(minuta <10){
      vrati += "0";
      vrati += minuta;
      return(vrati);
      }
      else{
      vrati += minuta;
      return(vrati);
      }
  }

   String vrati_sate(){
    DateTime now = rtc.now();
    int sati = now.hour();
    String vrati;
    if(sati <10){
      vrati += "0";
      vrati += sati;
      return(vrati);
      }
      else{
      vrati += sati;
      return(vrati);
      }
  }


int vrati_sekunde_asInt(){
   DateTime now = rtc.now();
    int sekunda = now.second();
    return sekunda;
  }

  void DevIcE_init(void)
{
  Wire.begin();
  mcp1.begin(0);
  for (int z = 1; z <= 16; z++){
    
    IO_write(z,INPUT_PULLUP);
    
    if(z <= 5){
     PWM_write(z,0);
    }
  }
}
 

  

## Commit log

2018-06-04 First library update for DevIcE Development Board
    Library is writen in C++
    Adafruit's library for MCP23017 is used to make thing easier.
2019-11-18 Merged all versions from other repos
    [BOM.xlsx, main_shema.brd, main_shema.sch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]

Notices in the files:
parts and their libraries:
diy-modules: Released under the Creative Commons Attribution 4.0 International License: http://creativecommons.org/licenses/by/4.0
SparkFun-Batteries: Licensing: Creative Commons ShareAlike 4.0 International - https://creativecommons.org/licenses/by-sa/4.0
